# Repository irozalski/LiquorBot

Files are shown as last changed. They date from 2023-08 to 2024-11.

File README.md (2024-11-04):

# 🤖 LiquorBot

### Automatic liquor dispensing machine  used for pouring several-layer shots.<br> 
### The project uses a stepper motor, liquid pumps, Hall sensor, optocouplers and LEDs controlled by the Esp32 microcontroller. <br>
### Most of the case parts were printed on a 3D printer.
---
## Electronic schematic <br> 
LiquorBot schematic

---
## PCB 3D visualisation <br> 


---

## Render of project <br>

Pouring_machine_project

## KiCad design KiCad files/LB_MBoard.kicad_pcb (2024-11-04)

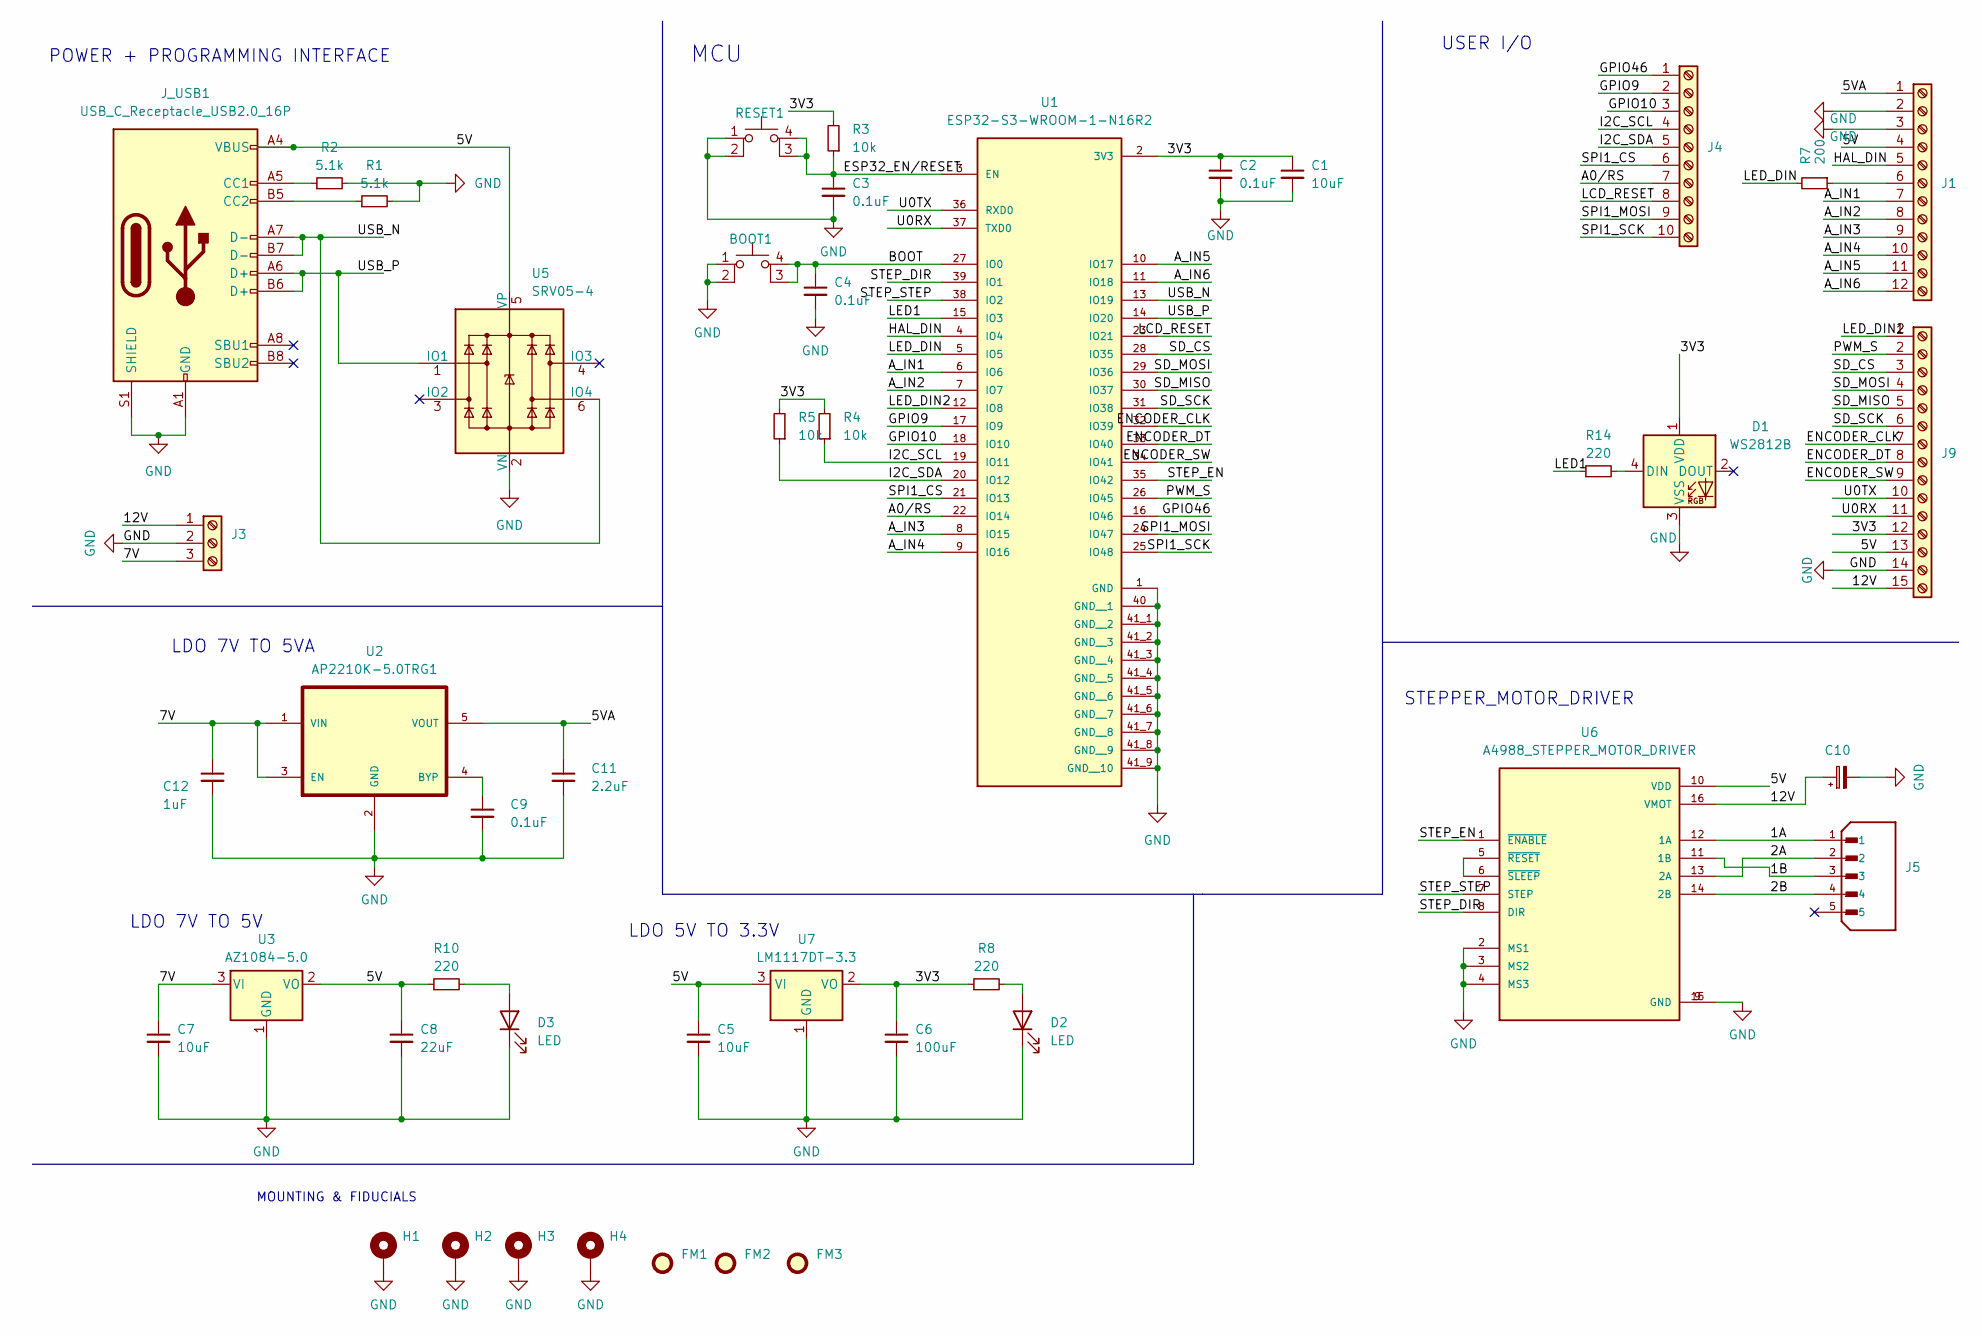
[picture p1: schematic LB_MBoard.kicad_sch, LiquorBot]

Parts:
BOOT1: SW_MEC_5E; SW_PTS_647_SN50_SMTR2_LFS
C1, C5, C7: 10uF; C_0805_2012Metric
C2, C3, C4, C9: 0.1uF; C_0805_2012Metric
C6: 100uF; C_0805_2012Metric
C8: 22uF; C_0805_2012Metric
C10: 100u; CAP_EEE1VA101XP
C11: 2.2uF; C_0805_2012Metric
C12: 1uF; C_0805_2012Metric
D1: WS2812B; LED_WS2812B_PLCC4_5.0x5.0mm_P3.2mm
D2, D3: LED; LED_0805_2012Metric
FM1, FM2, FM3: Fiducial; Fiducial_1mm_Mask2mm
H1, H2, H3, H4: MountingHole_Pad; MountingHole_3.2mm_M3_Pad_Via
J1: Screw_Terminal_01x12; 393570012
J3: Screw_Terminal_01x03; TerminalBlock_Phoenix_MKDS-1,5-3_1x03_P5.00mm_Horizontal
J4: Screw_Terminal_01x10; 393570010
J5: B5B-XH-A; JST_B5B-XH-A; PARTREV 7/4/21
J9: Screw_Terminal_01x15; 393570015
J_USB1: USB_C_Receptacle_USB2.0_16P; GCT_USB4085-GF-A_REVB
R1, R2: 5.1k; R_0805_2012Metric
R3, R4, R5: 10k; R_0805_2012Metric
R7: 200; R_0805_2012Metric
R8, R10, R14: 220; R_0805_2012Metric
RESET1: SW_MEC_5E; SW_PTS_647_SN50_SMTR2_LFS
U1: ESP32-S3-WROOM-1-N16R2; XCVR_ESP32-S3-WROOM-1U-N16; PARTREV v1.0
U2: AP2210K-5.0TRG1; SOT-23-5_RAW
U3: AZ1084-5.0; DPAK457P1010X238-3N
U5: SRV05-4; SOT-23-6
U6: A4988_STEPPER_MOTOR_DRIVER; MODULE_A4988_STEPPER_MOTOR_DRIVER_CARRIER
U7: LM1117DT-3.3; TO-252-3_TabPin2

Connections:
/1A: J5.1, U6.12 (1A)
/1B: J5.3, U6.11 (1B)
/2A: J5.2, U6.13 (2A)
/2B: J5.4, U6.14 (2B)
/3V3: C1.1, C2.1, C6.1, D1.1 (VDD), J9.12, R3.2, R4.2, R5.2, R8.1, U1.2 (3V3), U7.2 (VO)
/5V: C5.1, C8.1, J1.4, J9.13, J_USB1.A4 (VBUS), J_USB1.A9 (VBUS), J_USB1.B4 (VBUS), J_USB1.B9 (VBUS), R10.1, U3.2 (VO), U5.5 (VP), U6.10 (VDD), U7.3 (VI)
/5VA: C11.1, J1.1, U2.5 (VOUT)
/7V: C7.1, C12.1, J3.3, U2.1 (VIN), U2.3 (EN), U3.3 (VI)
/12V: C10.1, J3.1, J9.15, U6.16 (VMOT)
/A0/RS: J4.7, U1.22 (IO14)
/A_IN1: J1.7, U1.6 (IO6)
/A_IN2: J1.8, U1.7 (IO7)
/A_IN3: J1.9, U1.8 (IO15)
/A_IN4: J1.10, U1.9 (IO16)
/A_IN5: J1.11, U1.10 (IO17)
/A_IN6: J1.12, U1.11 (IO18)
/BOOT: BOOT1.3 (K), BOOT1.4 (A), C4.1, U1.27 (IO0); also elsewhere on the board
/ENCODER_CLK: J9.7, U1.32 (IO39)
/ENCODER_DT: J9.8, U1.33 (IO40)
/ENCODER_SW: J9.9, U1.34 (IO41)
/ESP32_EN/RESET: C3.1, R3.1, RESET1.3 (K), RESET1.4 (A), U1.3 (EN); also elsewhere on the board
/GPIO9: J4.2, U1.17 (IO9)
/GPIO10: J4.3, U1.18 (IO10)
/GPIO46: J4.1, U1.16 (IO46)
/HAL_DIN: J1.5, U1.4 (IO4)
/I2C_SCL: J4.4, R4.1, U1.19 (IO11)
/I2C_SDA: J4.5, R5.1, U1.20 (IO12)
/LCD_RESET: J4.8, U1.23 (IO21)
/LED1: R14.1, U1.15 (IO3)
/LED_DIN: R7.2, U1.5 (IO5)
/LED_DIN2: J9.1, U1.12 (IO8)
/PWM_S: J9.2, U1.26 (IO45)
/SD_CS: J9.3, U1.28 (IO35)
/SD_MISO: J9.5, U1.30 (IO37)
/SD_MOSI: J9.4, U1.29 (IO36)
/SD_SCK: J9.6, U1.31 (IO38)
/SPI1_CS: J4.6, U1.21 (IO13)
/SPI1_MOSI: J4.9, U1.24 (IO47)
/SPI1_SCK: J4.10, U1.25 (IO48)
/STEP_DIR: U1.39 (IO1), U6.8 (DIR)
/STEP_EN: U1.35 (IO42), U6.1 (~ENABLE)
/STEP_STEP: U1.38 (IO2), U6.7 (STEP)
/U0RX: J9.11, U1.37 (TXD0)
/U0TX: J9.10, U1.36 (RXD0)
/USB_N: J_USB1.A7 (D-), J_USB1.B7 (D-), U1.13 (IO19), U5.6 (IO4)
/USB_P: J_USB1.A6 (D+), J_USB1.B6 (D+), U1.14 (IO20), U5.1 (IO1)
GND: BOOT1.1, BOOT1.2, C1.2, C2.2, C3.2, C4.2, C5.2, C6.2, C7.2, C8.2, C9.2, C10.2, C11.2, C12.2, D1.3 (VSS), D2.1 (K), D3.1 (K), H1.1, H2.1, H3.1, H4.1, J1.2, J1.3, J3.2, J9.14, J_USB1.A1 (GND), J_USB1.A12 (GND), J_USB1.B1 (GND), J_USB1.B12 (GND), J_USB1.S1 (SHIELD), J_USB1.S2, J_USB1.S3, J_USB1.S4, R1.2, R2.2, RESET1.1, RESET1.2, U1.1 (GND), U1.40 (GND__1), U1.41_1 (GND__2), U1.41_2 (GND__3), U1.41_3 (GND__4), U1.41_4 (GND__5), U1.41_5 (GND__6), U1.41_6 (GND__7), U1.41_7 (GND__8), U1.41_8 (GND__9), U1.41_9 (GND__10), U1.41_10, U1.41_11, U1.41_12, U1.41_13, U1.41_14, U1.41_15, U1.41_16, U1.41_17, U1.41_18, U1.41_19, U1.41_20, U1.41_21, U2.2 (GND), U3.1 (GND), U5.2 (VN), U6.2 (MS1), U6.3 (MS2), U6.4 (MS3), U6.9 (GND), U6.15 (GND), U7.1 (GND); also elsewhere on the board
unnamed: D1.4 (DIN), R14.2
unnamed: D2.2 (A), R8.2
unnamed: D3.2 (A), R10.2
unnamed: J1.6, R7.1
unnamed: J_USB1.A5 (CC1), R2.1
unnamed: J_USB1.B5 (CC2), R1.1
unnamed: C9.1, U2.4 (BYP)
unnamed: U6.5 (~RESET), U6.6 (~SLEEP)

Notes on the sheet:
USER I/O
STEPPER_MOTOR_DRIVER
MCU
LDO 7V TO 5V
MOUNTING & FIDUCIALS
LDO 5V TO 3.3V
POWER + PROGRAMMING INTERFACE
LDO 7V TO 5VA

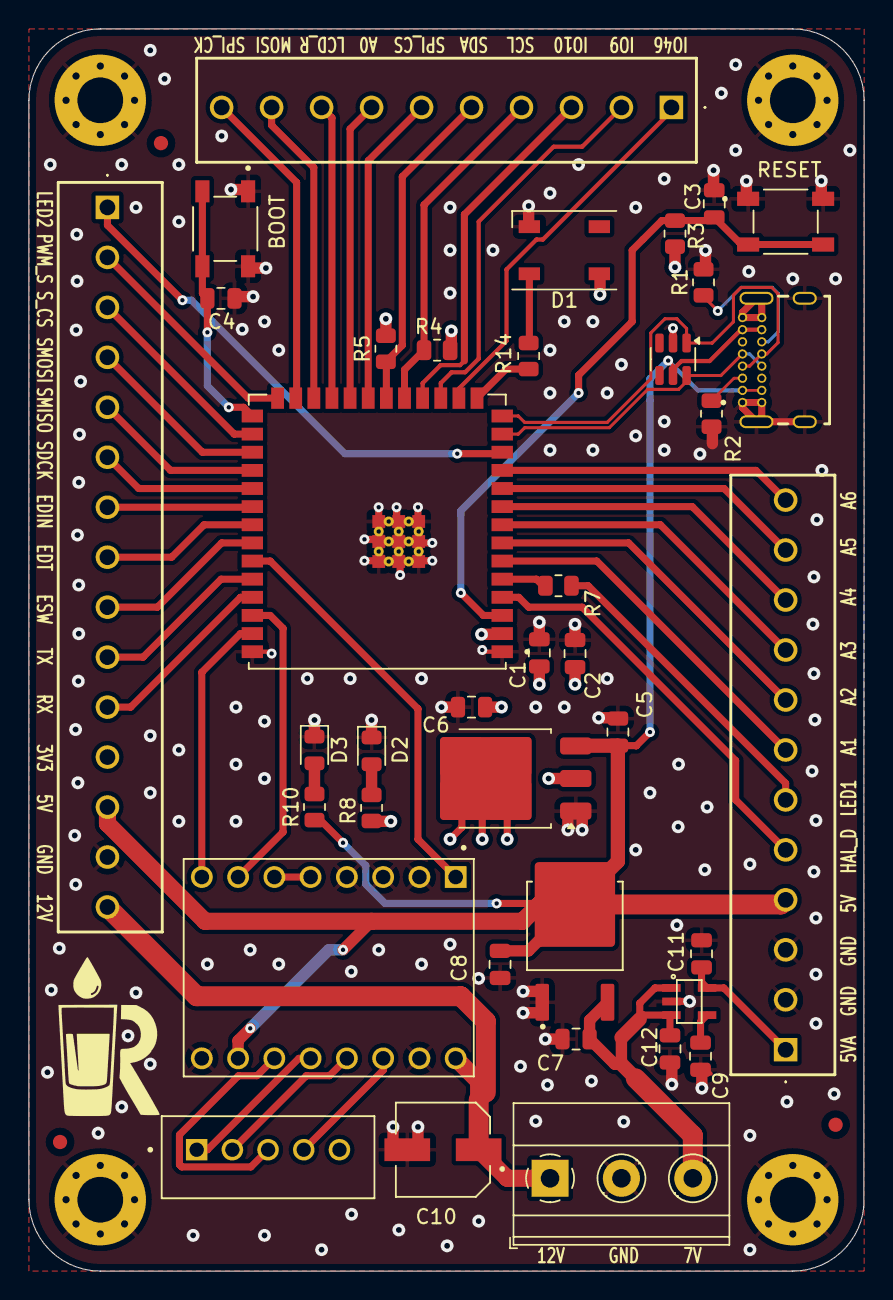
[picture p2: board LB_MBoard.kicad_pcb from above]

Board: 4 copper layers, 58.5 x 87.0 mm, 45 parts (0 on the bottom side), 55 nets.

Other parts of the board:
BOOT: SW_MEC_5E; SW_PTS_647_SN50_SMTR2_LFS
RESET: SW_MEC_5E; SW_PTS_647_SN50_SMTR2_LFS

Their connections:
/BOOT: BOOT.3 (K), BOOT.4 (A); also elsewhere on the board
/ESP32_EN/RESET: RESET.3 (K), RESET.4 (A); also elsewhere on the board
GND: BOOT.1, BOOT.2, RESET.1, RESET.2; also elsewhere on the board

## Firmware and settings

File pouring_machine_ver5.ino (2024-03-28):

#include <Adafruit_NeoPixel.h>
#include <AccelStepper.h>

//LEDs
#define LED_COUNT 30
#define LED_PIN    6

//First pump Led change
int inProgressLed1 = 0;
int inProgressLed2 = 0;
int inProgressLed3 = 0;


Adafruit_NeoPixel strip(LED_COUNT, LED_PIN, NEO_GRB + NEO_KHZ800);

// PUMP A

const int enableA = 3; //pwm pin
const int in1 = 4;
const int in2 = 5;

// PUMP B

const int enableB = 9; //pwm pin
const int in3 = 8;
const int in4 = 7;

//STEPPER
#define DIR_PIN 12
#define STEP_PIN 11
#define ENABLE 13

//const int STEPS_PER_REVOLUTION = 2048;

const float MAX_SPEED = 1200;    // steps per second
const float ACCELERATION = 500; 

//BUTTONS
#define START_BUTTON_PIN A5
#define BUTTON_PIN1 A0
#define BUTTON_PIN2 A1
#define BUTTON_PIN3 A2

int buttonState1 = 0;
int buttonState2 = 0;
int buttonState3 = 0;

//Hall sensor
#define HALL_SENSOR 2
int hallState;
int previousHallState = HIGH;

// correct values below
//const int fullCircle = 11580;
//const int stepCircle = 1930;
// test values below
//const int fullCircle = 2316;
//const int stepCircle = 386;


int n = 1;

boolean changestate = 0;
boolean changeDirection = 0;

boolean pumpStartDelay1 = false;
boolean pumpStartDelay2 = false;

boolean inProgressLedForPump1Off = false;

//MILLIS
unsigned long previousMillis = 0;  // Variable to store the last time the command was executed
const unsigned long delayTime = 3000;  // Time to delay in milliseconds
const unsigned long delayTime2 = 6000;  // Time to delay in milliseconds
const unsigned long pumpDelayTime1 = 1000; //Start after 1 second and ends after 3 sec: 2 sec work time
const unsigned long pumpDelayTime2 = 4000; //Start after 4 seconds and ends after 6 sec: 2 sec work time


// Define a stepper and the pins it will use
// 1 or AccelStepper::DRIVER means a stepper driver (with Step and Direction pins)
AccelStepper stepper(1, STEP_PIN, DIR_PIN); //type (1) of stepper motor not the FULL2WIRE- look up to AccelStepper library 

void setup() {
  
  //LEDs
  strip.begin();
  strip.show();

   //start animation
  led_on(0,6,255,255,255);
  delay(100);
  led_on(0,6,0,0,0);
  delay(200);
  led_on(0,6,255,255,255);
  delay(500);
  fade_in(0, 6);
  //fade_out(0, 6);
  
  //strip.setBrightness(50);

  //PUMP A
  pinMode(enableA, OUTPUT);
  pinMode(in1, OUTPUT);
  pinMode(in2, OUTPUT);

  //PUMP B
  pinMode(enableB, OUTPUT);
  pinMode(in3, OUTPUT);
  pinMode(in4, OUTPUT);
  
  //BUTTONS
  pinMode(START_BUTTON_PIN, INPUT_PULLUP);
  pinMode(BUTTON_PIN1, INPUT_PULLUP);
  pinMode(BUTTON_PIN2, INPUT_PULLUP);
  pinMode(BUTTON_PIN3, INPUT_PULLUP);

  //STEPPER
  stepper.setMaxSpeed(MAX_SPEED);
  stepper.setAcceleration(ACCELERATION);
  //pinMode(DIR_PIN, OUTPUT);
  //digitalWrite(DIR_PIN, HIGH);
  
  stepper.setEnablePin(ENABLE);
  
  //specify that the enable pin is inverted
  stepper.setPinsInverted(false, false, true);
  //stepper.enableOutputs();
  //pinMode(ENABLE, OUTPUT);
  //setEnablePin(ENABLE);

  //HALL SENSOR
  pinMode(HALL_SENSOR, INPUT);
  Serial.begin(9600);
  
  

}

void loop() {
  
  hallState = digitalRead(HALL_SENSOR);
  Serial.println(hallState);
  
  buttonState1 = digitalRead(BUTTON_PIN1);
  buttonState2 = digitalRead(BUTTON_PIN2);
  buttonState3 = digitalRead(BUTTON_PIN3);

  analogWrite (enableA, 255); //Voltage regulation of motorA
  analogWrite (enableB, 255); //Voltage regulation of motorB

   switch(buttonState1)
{
case LOW:
    switch(inProgressLed1)
    {
      case 1:
      led_on(0,3,255,255,0);
      break;
      
      case 2:
      led_on(0,3,255,0,255);
      break;
      
      default:
      led_on(0,3,0,255,0);
      break;
    }  
    break;
    
  default:
  led_off(0,3);
  break;
}

switch(buttonState2)
{
case LOW:
    switch(inProgressLed2)
    {
      case 1:
      led_on(3,6,255,255,0);
      break;

      case 2:
      led_on(3,6,255,0,255);
      break;
      
      default:
      led_on(3,6,0,255,0);
      break;
    }
    break;
    
  default:
  led_off(3,6);
  break;
}

switch(buttonState3)
{
case LOW:
    switch(inProgressLed3)
    {
      case 1:
      led_on(6,9,255,255,0);
      break;

      case 2:
      led_on(6,9,255,0,255);
      break;
      
      default:
      led_on(6,9,0,255,0);
      break;
    }
    
    break;
  default:
  led_off(6,9);
  break;
}
  
  if (int buttonState4 = digitalRead(START_BUTTON_PIN) == LOW) {
    delay(200);
    changestate = 1;
    n=1;
    stepper.setCurrentPosition(0);
  }
  
  if (changestate == 1) {
    //stepper.moveTo(fullCircle);
    if(changeDirection == 0){
    stepper.setSpeed(MAX_SPEED);
    }
    else{
      stepper.setSpeed(-MAX_SPEED);
    }
    unsigned long currentMillis = millis();

    //First pump
    if (currentMillis - previousMillis >= pumpDelayTime1 && pumpStartDelay1 == true){
       //Pump start
        digitalWrite(in1, HIGH);
        digitalWrite(in2, LOW);

        //Leds change 
        // have to check value of n incremented by 1 because of n++ at the and of the loop that is always added
        if (n==2){
        inProgressLed1 = 1;
        }
        if (n==3){
        inProgressLed2 = 1;
        }
        if (n==4){
        inProgressLed3 = 1;
        }
        pumpStartDelay1 = false;
        inProgressLedForPump1Off = true;
    }
    
    //Second pump
    if (currentMillis - previousMillis >= pumpDelayTime2 && pumpStartDelay2 == true){
       //Pump start
        digitalWrite(in3, HIGH);
        digitalWrite(in4, LOW);

        //Leds change 
        // have to check value of n incremented by 1 because of n++ at the and of the loop that is always added
        if (n==2){
        inProgressLed1 = 2;
        }
        if (n==3){
        inProgressLed2 = 2;
        }
        if (n==4){
        inProgressLed3 = 2;
        }
        pumpStartDelay2 = false;
    }

    //Pump 1 Stop
    if (currentMillis - previousMillis >= delayTime){
    //Pump 1 stop
    digitalWrite(in1, LOW);
    digitalWrite(in2, LOW);
    
    if (inProgressLedForPump1Off == true){
    //Leds reset, it should work only once 
    inProgressLed1 = 0;
    inProgressLed2 = 0;
    inProgressLed3 = 0;
    inProgressLedForPump1Off = false;
      }
    }

    //Pump 2 Stop and continuation of program
    if (currentMillis - previousMillis >= delayTime2){
    //Pump 2 stop
    digitalWrite(in3, LOW);
    digitalWrite(in4, LOW);
    //Leds reset
    inProgressLed1 = 0;
    inProgressLed2 = 0;
    inProgressLed3 = 0;
    stepper.enableOutputs();
    stepper.run();
    }
    
    if (hallState != previousHallState){ // tylko jak zmieni sie z 1 na 0
      previousHallState = hallState;
     if (hallState == LOW) {
      if (n==1 && buttonState1 == LOW){
        stepper.stop();   
        previousMillis = currentMillis; 
        pumpStartDelay1 = true;
        pumpStartDelay2 = true;
       

        
        
      }
      if (n==2 && buttonState2 == LOW){    
        stepper.stop();
        previousMillis = currentMillis; 
        
        pumpStartDelay1 = true;
        pumpStartDelay2 = true;
      }
      if (n==3 && buttonState3 == LOW){
        stepper.stop();
        previousMillis = currentMillis;
         
        pumpStartDelay1 = true;
        pumpStartDelay2 = true;
      }
      n++;  
    }
    }
  
  if (n == 7){
      stepper.stop();
      //delay(2000);
      changestate = 0;
      changeDirection = !changeDirection;
      stepper.disableOutputs();
       
    }
  }
}

//LED function

void led_on (int x, int y, int r, int g, int b) {
  for(int i=x; i<y; i++) {
    strip.setPixelColor(i, r, g, b);
    }
    strip.show();
}

void led_off (int x, int y) {
  for(int i=x; i<y; i++) {
    strip.setPixelColor(i, 255, 0, 0);
    }
    strip.show();
}

void fade_in (int x, int y) {
  for(int j = 0; j<255; j++) {
    for(int i=x; i<y; i++) {
      strip.setPixelColor(i, j, 0, 0);
      }
    strip.show();
    delay(10);
  }
}


void fade_out (int x, int y) {
  for(int j = 255; j>0; j--) {
    for(int i=x; i<y; i++) {
      strip.setPixelColor(i, j, j, j);
      }
    strip.show();
    delay(5);
  }
}

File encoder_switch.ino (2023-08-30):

#include <Servo.h>
#include <Adafruit_NeoPixel.h>

#define LED_COUNT 30
#define LED_PIN    11

Adafruit_NeoPixel strip(LED_COUNT, LED_PIN, NEO_GRB + NEO_KHZ800);

#define encoderCLK 4
#define encoderDT 5
#define encoderBUTTON 12
int buttonState = HIGH;

int counter = 0;
int state;
int lastState;

Servo servomotor;
//byte servo_position = 0;

bool conditionMet = false;

void setup() {
  Serial.begin(9600);

  strip.begin();
  strip.show();
  strip.setBrightness(50);
  
  pinMode(encoderCLK, INPUT);
  pinMode(encoderDT, INPUT);
  pinMode (encoderBUTTON, INPUT_PULLUP);
  
  lastState = digitalRead(encoderCLK);

  servomotor.attach(9);
  //servomotor.write(servo_position);

  if (!conditionMet) {
    Serial.println("fct 000");
    led_on(0,30,0);
    conditionMet = true; // Set the flag to indicate the condition has been met
  }
  
}

void loop() {
  
  buttonState = digitalRead(encoderBUTTON);    // Read the digital value of the switch (LOW/HIGH)
  // If the switch is pressed (LOW), print message
  if (buttonState == LOW) {
      Serial.println("Switch pressed");
      counter=0;
  }
  
  state = digitalRead(encoderCLK);
  if(state != lastState){
    if(digitalRead(encoderDT) != state){
      counter +=2;
      if(counter>36){
        counter=0;
      }
    }
    else{
      counter -=2;
      if(counter<0){
        counter=36;
      }
    }
    servomotor.write(counter);
    Serial.println(counter);

    if (counter >= 0 && counter < 12) {
    Serial.println("fct 000");
    led_on(0,30,0);
    } 
    else if (counter >= 13 && counter < 24) {
    Serial.println("fct 111");
    led_on(0,30,255);
    }
    else if (counter >= 25 && counter < 36) {
    Serial.println("fct 222");
    led_on(0,30,100);
    }
  }
  lastState = state;
}

void led_on (int x, int y, int z) {
  for(int i=x; i<y; i++) {
    strip.setPixelColor(i, 255, 0, z);
    }
    strip.show();
}

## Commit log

2024-03-10 Update pouring_machine_ver1.ino
    Further testing. Pump control with the L298N H-bridge circuit was added as well as better visualization of the pouring process with LEDs.
2024-03-12 Further testing.
    Further testing. Pump and LEDs delay was added.
2024-03-13 Second pump was added, further tests.
2024-03-23 New version
    Replacement with a bipolar motor and new motor driver
    [pouring_machine_ver4.ino]
2024-03-24 New version with hall effect sensor
    Hall effect sensor was added instead of step counting. Stepper motor direction is now different every time.
2024-11-04 Adding KiCad files
    [LB_MBoard.kicad_pcb, LB_MBoard.kicad_sch]
